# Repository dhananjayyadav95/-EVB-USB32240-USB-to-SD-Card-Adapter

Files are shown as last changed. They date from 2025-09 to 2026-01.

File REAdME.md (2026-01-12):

# EVB-USB32240 USB to SD Card Adapter

An open-source hardware design for a USB to SD card adapter board based on the USB32240 controller.

## Features

- USB Type-A interface
- Micro SD card slot support
- 3.3V voltage regulation using LM3480-3.3
- Crystal oscillator for clock generation
- Status LED indicator
- SMD components for compact design

## Hardware Specifications

- **USB Interface**: USB Type-A connector
- **SD Card**: Micro SD card slot
- **Voltage Regulator**: LM3480-3.3 for 3.3V power supply
- **Crystal**: External crystal for clock generation
- **Form Factor**: Compact SMD design
- **PCB Layers**: 2-layer board (F.Cu and B.Cu)

## Key Components

- USB32240 controller in QFN-36 package
- LM3480-3.3 voltage regulator in SOT-23 package
- Various 0201, 0402 resistors and capacitors
- Status LED for operation indication
- Crystal oscillator for stable timing

## Project Structure

```
EVB-USB32240/
├── EVB-USB32240.kicad_pcb   # PCB layout file
├── EVB-USB32240.kicad_sch   # Schematic file
├── EVB-USB32240.kicad_pro   # Project file
└── EVB-USB32240-backups/    # Backup files
```

## Manufacturing

The board is designed to be manufactured using standard PCB fabrication processes:
- 2-layer PCB
- Standard FR4 material
- Components are primarily SMD for automated assembly
- Minimal via count for cost optimization

## License

This hardware design is released under MIT License

## Contributing

Contributions to improve the design are welcome. Please feel free to:
- Submit bug reports
- Propose design improvements
- Create pull requests

## Acknowledgments

- KiCad EDA for the design tools
- Contributors and reviewers

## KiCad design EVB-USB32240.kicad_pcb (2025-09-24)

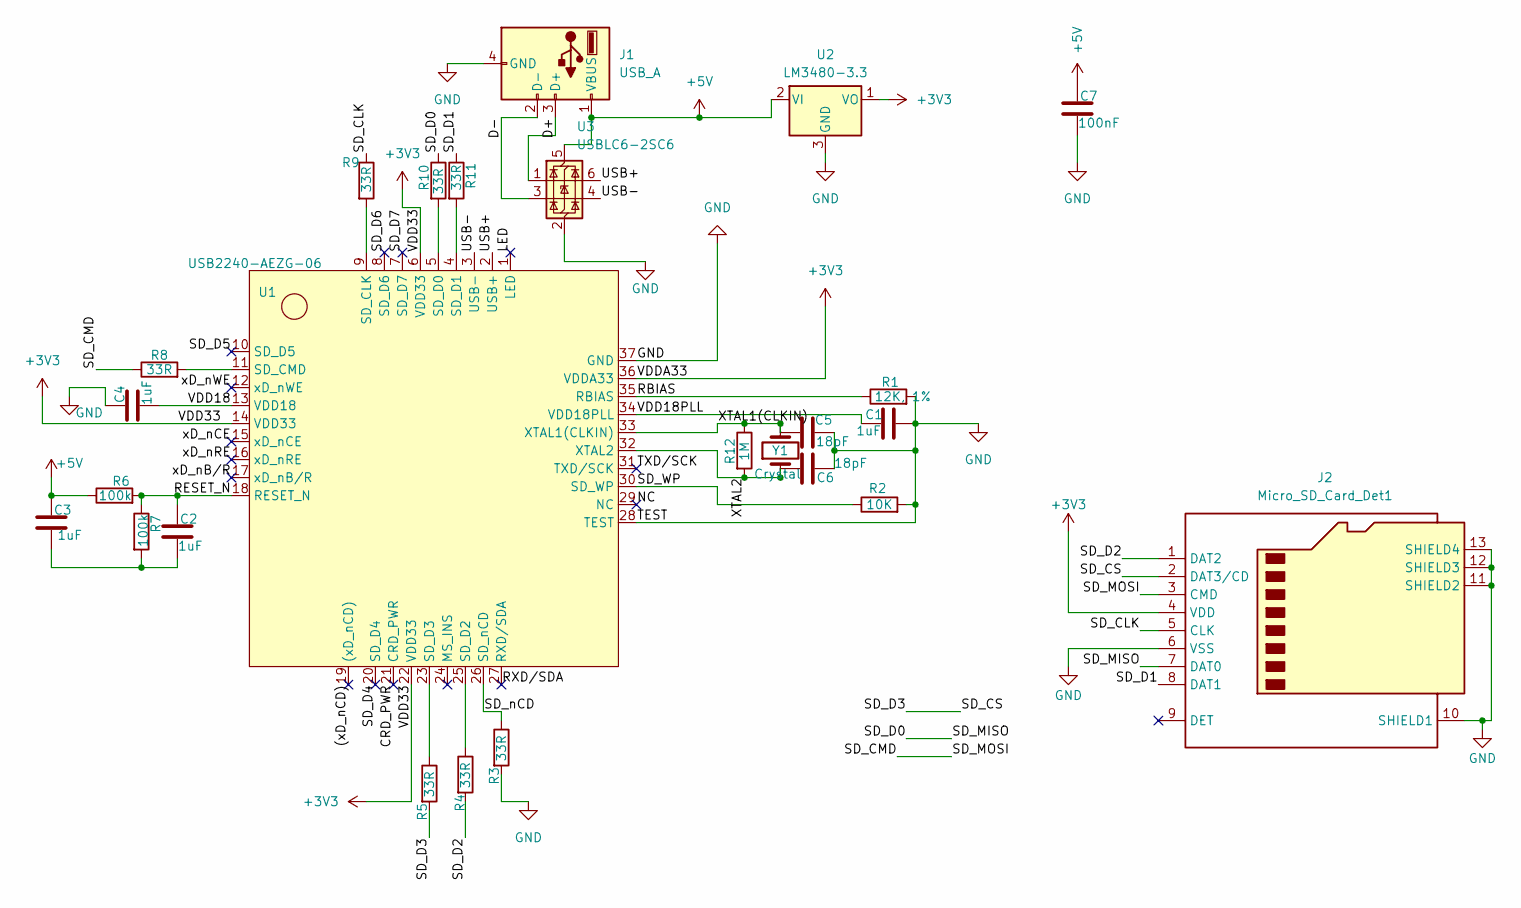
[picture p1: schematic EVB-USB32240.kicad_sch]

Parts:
C1: 1uF; C_0402_1005Metric
C2, C3, C4: 1uF; C_0201_0603Metric
C5, C6: 18pF; C_0402_1005Metric
C7: 100nF; C_0201_0603Metric
J1: USB_A; USB_A_Connfly_DS1095
J2: Micro_SD_Card_Det1; TF-SMD_TF-02
R1: 12K, 1%; R_0402_1005Metric
R2: 10K; R_0402_1005Metric
R3, R4, R5, R8, R9, R10, R11: 33R; R_0201_0603Metric
R6, R7: 100k; R_0201_0603Metric
R12: 1M; R_0402_1005Metric
U1: USB2240-AEZG-06; QFN-36_L6.0-W6.0-P0.50-TL-EP4.1; LCSC Part C633328
U2: LM3480-3.3; SOT-23
U3: USBLC6-2SC6; SOT-23-6
Y1: Crystal; Crystal_SMD_HC49-SD

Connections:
+3V3: J2.4 (VDD), U1.6 (VDD33), U1.14 (VDD33), U1.22 (VDD33), U1.36 (VDDA33), U2.1 (VO)
+5V: C3.1, C7.1, J1.1 (VBUS), R6.1, U2.2 (VI), U3.5 (VBUS)
/(xD_nCD): U1.19 ((xD_nCD))
/CRD_PWR: U1.21 (CRD_PWR)
/D+: J1.3 (D+), U3.1 (I/O1)
/D-: J1.2 (D-), U3.3 (I/O2)
/LED: U1.1 (LED)
/NC: U1.29 (NC)
/RBIAS: R1.1, U1.35 (RBIAS)
/RESET_N: C2.1, R6.2, R7.1, U1.18 (RESET_N)
/RXD/SDA: U1.27 (RXD/SDA)
/SD_CLK: J2.5 (CLK), R9.1
/SD_CMD: J2.3 (CMD), R8.1
/SD_CS: J2.2 (DAT3/CD), R5.2
/SD_D0: J2.7 (DAT0), R10.1
/SD_D1: J2.8 (DAT1), R11.1
/SD_D2: J2.1 (DAT2), R4.2
/SD_D4: U1.20 (SD_D4)
/SD_D5: U1.10 (SD_D5)
/SD_D6: U1.8 (SD_D6)
/SD_D7: U1.7 (SD_D7)
/SD_WP: R2.1, U1.30 (SD_WP)
/SD_nCD: R3.1, U1.26 (SD_nCD)
/TXD/SCK: U1.31 (TXD/SCK)
/USB+: U1.2 (USB+), U3.6 (I/O1)
/USB-: U1.3 (USB-), U3.4 (I/O2)
/VDD18: C4.2, U1.13 (VDD18)
/VDD18PLL: C1.1, U1.34 (VDD18PLL)
/XTAL1(CLKIN): C5.1, R12.1, U1.33 (XTAL1(CLKIN)), Y1.2
/XTAL2: C6.1, R12.2, U1.32 (XTAL2), Y1.1
/xD_nB/R: U1.17 (xD_nB/R)
/xD_nCE: U1.15 (xD_nCE)
/xD_nRE: U1.16 (xD_nRE)
/xD_nWE: U1.12 (xD_nWE)
GND: C1.2, C4.1, C5.2, C6.2, C7.2, J1.4 (GND), J2.6 (VSS), J2.10 (SHIELD1), J2.11 (SHIELD2), J2.12 (SHIELD3), J2.13 (SHIELD4), R1.2, R2.2, R3.2, U1.28 (TEST), U1.37 (GND), U2.3 (GND), U3.2 (GND)
unnamed: C2.2, C3.2, R7.2
unnamed: R9.2, U1.9 (SD_CLK)
unnamed: R8.2, U1.11 (SD_CMD)
unnamed: R10.2, U1.5 (SD_D0)
unnamed: R11.2, U1.4 (SD_D1)
unnamed: R4.1, U1.25 (SD_D2)
unnamed: R5.1, U1.23 (SD_D3)

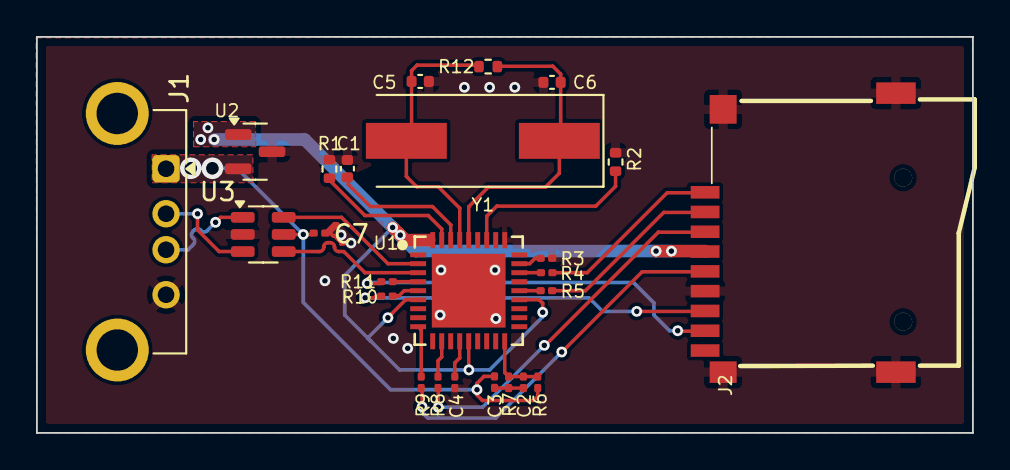
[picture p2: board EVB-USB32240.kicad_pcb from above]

Board: 2 copper layers, 52.0 x 22.0 mm, 25 parts (0 on the bottom side), 28 nets.
